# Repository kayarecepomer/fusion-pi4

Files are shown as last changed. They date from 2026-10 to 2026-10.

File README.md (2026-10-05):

# fusion-pi4: foldable PiDeck cyberdeck

A remix of the [PiDeck 7-inch cyberdeck with Raspberry Pi 5](https://makerworld.com/en/models/2619704-pideck-7-inch-cyberdeck-with-raspberry-pi-5)
into a foldable, small-laptop form factor. It reuses the original build's parts
(7" display, keyboard, Raspberry Pi 5, screws and hardware); only the printed
enclosure changes, splitting into a screen lid and a keyboard base joined by a hinge.

Designed in Autodesk Fusion.

## Repository layout

| Folder | Contents |
|---|---|
| `cad/fusion/` | Native Fusion archives (`.f3d`, or `.f3z` for multi-component designs). The editable source of truth. |
| `cad/cadquery/` | Parametric CadQuery script that generates the STEP and STL files. |
| `cad/step/` | STEP exports (`.step`) so the model opens in any CAD tool. |
| `stl/` | Print-ready meshes (`.stl` or `.3mf`), one file per printed part. |
| `docs/` | Notes, the export guide and the design report. |

## Getting the model

- **Edit it:** open `cad/fusion/*.f3d` in Fusion via *File > Open > Open from my computer*.
- **Other CAD tools (FreeCAD, Onshape, SolidWorks):** import `cad/step/*.step`.
- **Print it:** slice the files in `stl/`.

## Adding new work

See [docs/exporting-from-fusion.md](docs/exporting-from-fusion.md) for how to
export from Fusion and which file goes where.

## Current design (draft 3)

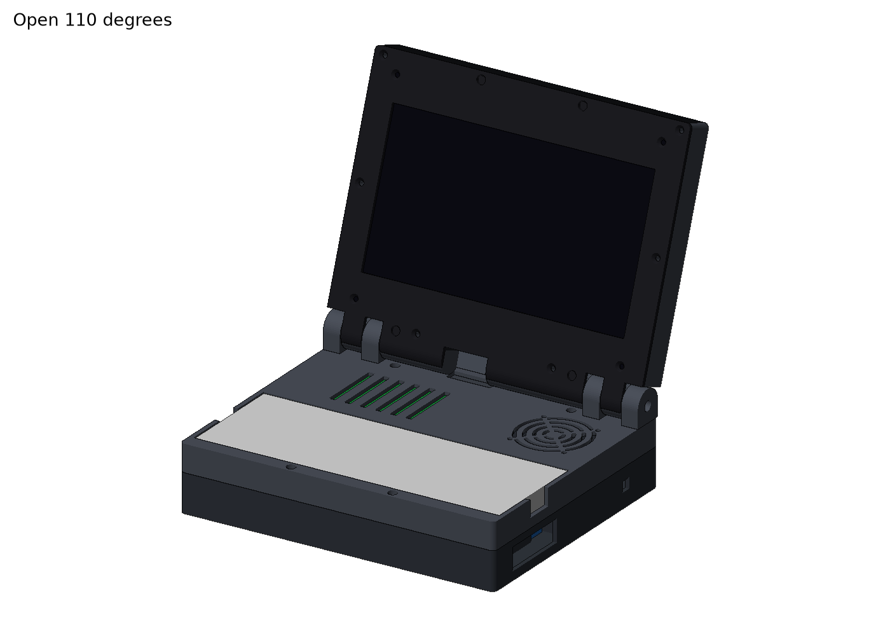
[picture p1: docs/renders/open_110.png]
open


The first draft is a parametric [CadQuery](https://cadquery.readthedocs.io) script in
`cad/cadquery/`, sized from PiDeck V1's own STEP assembly. It writes the STEP files to
`cad/step/` and the print-ready STLs to `stl/`. The design report is in
[docs/foldable-laptop-report.md](docs/foldable-laptop-report.md).

```bash
pip install cadquery
python cad/cadquery/foldable_laptop.py && python cad/cadquery/check_fit.py && python cad/cadquery/render.py
```

## License

Remix of PiDeck by Screase3D, shared under the same CC BY-NC-SA 4.0 license.

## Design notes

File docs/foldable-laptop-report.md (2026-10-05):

# Foldable PiDeck: design report (draft 3)

A clamshell remix of the [PiDeck 7" cyberdeck](https://makerworld.com/en/models/2619704-pideck-7-inch-cyberdeck-with-raspberry-pi-5)
that keeps PiDeck's parts (Raspberry Pi 5 + Waveshare NVMe HAT, 7" IPS touch LCD,
Rii X1 mini keyboard, Anker power bank, M2.5 screws + heat-set inserts, 5x2 magnets)
but folds like a small laptop.

Part sizes are measured from PiDeck V1's own STEP assembly
(`Pi_Deck_RaspberryPi5.step`, see `docs/components.md`). Draft 3 drops PiDeck's
Waveshare IO adapter in favour of short cables, as kaya chose, which makes the base
20 mm shallower.

open

## 1. What is in this draft

| File | What it is |
|---|---|
| `cad/cadquery/foldable_laptop.py` | The whole model as a parametric CadQuery script. All bought-part sizes sit in one `Parts` block. |
| `cad/cadquery/check_fit.py` | Checks every printed part is one valid solid, that no part collides with the keyboard, power bank, Pi block or display, and that the lid swings 0 to 150 degrees without hitting the base. |
| `cad/cadquery/render.py` | Makes the PNG previews in `docs/renders/` (software renderer, no GPU needed). |
| `cad/step/*.step` | One STEP per printed part, plus `foldable-assembly-closed.step` and `foldable-assembly-open.step` (110 degrees) with the bought parts as coloured dummies. |
| `stl/*.stl` | Print-ready meshes, already rotated into print orientation. |

Rebuild everything after changing a number:

```bash
pip install cadquery
python cad/cadquery/foldable_laptop.py   # STEP into cad/step/, STL into stl/
python cad/cadquery/check_fit.py         # must end with "ALL OK"
python cad/cadquery/render.py            # refresh docs/renders/*.png
```

### Opening it in Fusion

Use **File > Open > Open from my computer** (or Upload in the Data Panel) on
`cad/step/foldable-assembly-closed.step`. Fusion imports STEP as real B-rep bodies, one
component per part, so you can sketch on faces, add fillets and move holes like a
native design. If you carry on in Fusion, export the `.f3d` into `cad/fusion/` as
described in `docs/exporting-from-fusion.md`. The script stays the source of truth for the big dimensions; Fusion is
the right place for styling (chamfers, logos, texture) once the layout is settled.

## 2. Overall layout

| | Draft 3 (no IO adapter) | Draft 2 (with IO adapter) | Draft 1 (datasheet guesses) |
|---|---|---|---|
| Footprint (base and lid) | **186 x 154 mm** | 186 x 174 | 180 x 136 |
| Base height | **38.2 mm** | 38.2 | 36.8 |
| Lid thickness | **18.6 mm** | 18.6 | 15.5 |
| Closed thickness | **56.8 mm** | 56.8 | 52.3 |
| Open angle tested | 0 to 150 degrees, no collisions | same | same |

What changed the size:
- The keyboard is **179.4** mm wide (not 152), so the case is 186 wide.
- The screen module is **124.2** mm tall and **14.1** thick including its driver board
  (not 100 x 11), so the lid is deeper and thicker.
- PiDeck's "IO board" is an adapter that plugs into the Pi's micro-HDMI and USB-C edge
  and sticks out 34.6 mm past it. Without it, the Pi + HAT block is
  **90 x 58 x 26.1** mm. The depth (154 mm) is now set by the lid: the 124.2 mm screen
  plus the hinge.

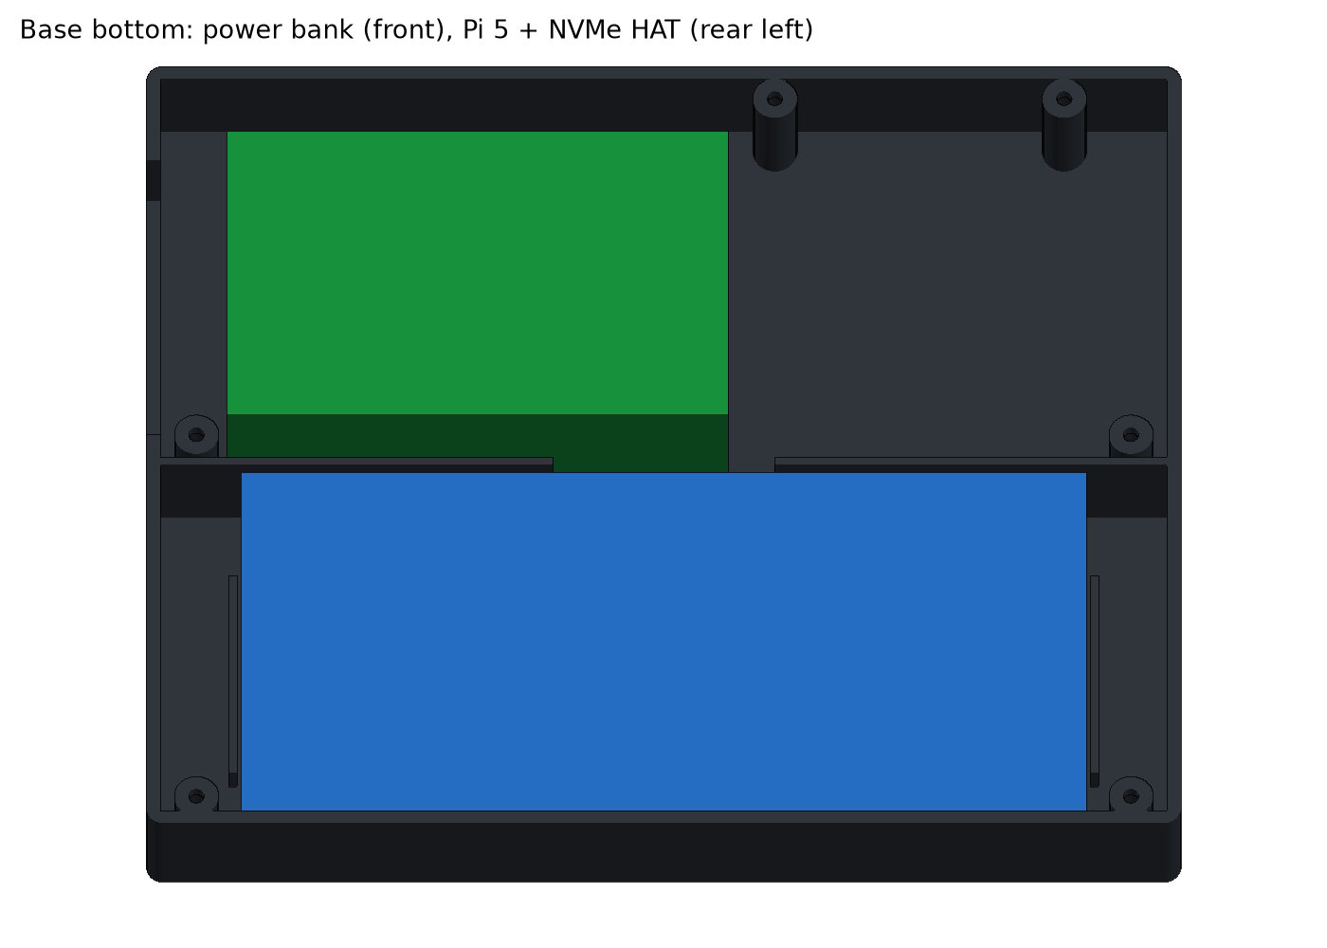
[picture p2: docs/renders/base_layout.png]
layout


**Base, front half:** the power bank lies flat in a bay on the floor. The keyboard
sits on top of it in a pocket in the deck, flush with the surface so the lid closes
flat. Thumb scoops at both ends of the pocket let you lift the keyboard out.

**Base, rear half:** the Pi + HAT sits rear-left, right behind the keyboard, on four
standoffs with M2.5 heat-set inserts (the SSD hangs under the HAT between them). Its
USB and Ethernet ports face the left wall; the Pi sits 12 mm in from the wall behind an
I/O window, so plugs with chunky overmoulds still fit. Its micro-HDMI and USB-C edge
faces the hinge with a 15.7 mm gap for right-angle plugs: the display ribbon goes
straight up from the micro-HDMI port through the hinge, and the USB-C is fed from the
power bank inside. The right-rear bay holds the optional 4010 fan (under a grill in the
deck), the 6x6 power button in the right wall, and the wiring. A window in the right
wall reaches the power bank's port.

**Lid:** the screen sits face down in the lid when closed, held between a 2 mm bezel
and pressure pads on the back shell. Corner locators centre it, and its own four
mounting holes (157.0 x 114.9 pattern) line up with countersunk M2.5 holes in the bezel,
so it can be screwed in with nuts on the back of the frame. The chin under the screen
(next to the hinge) is about 22 mm.

**Latch:** the 8 magnets from the PiDeck kit are reused as 4 pairs, two at the front
edge and two near the hinge, pressed into blind pockets in the deck and the bezel.

## 3. Printed parts

| Part | Print size (mm) | Orientation | Fasteners |
|---|---|---|---|
| `base-bottom` | 186 x 154 x 22.5 | floor down | 6x M2.5x8 countersunk, from deep counterbores in the underside up into `base-top` |
| `base-top` | 186 x 154 x 15.7 | deck face down, no supports | 6 heat-set inserts |
| `hinge-knuckle-left/right-outer`, `hinge-knuckle-left/right-inner` (4 parts) | 18.6 x 18.6 x 10 | on their side, bore vertical | 2x M2.5x8 each from under the deck, insert in the knuckle |
| `lid-back` | 186 x 154 x 16.6 | back plate down | 6 heat-set inserts |
| `lid-bezel` | 186 x 151 x 3 | face down | 6x M2.5x6 countersunk, plus 4x M2.5 + nuts through the screen's holes |

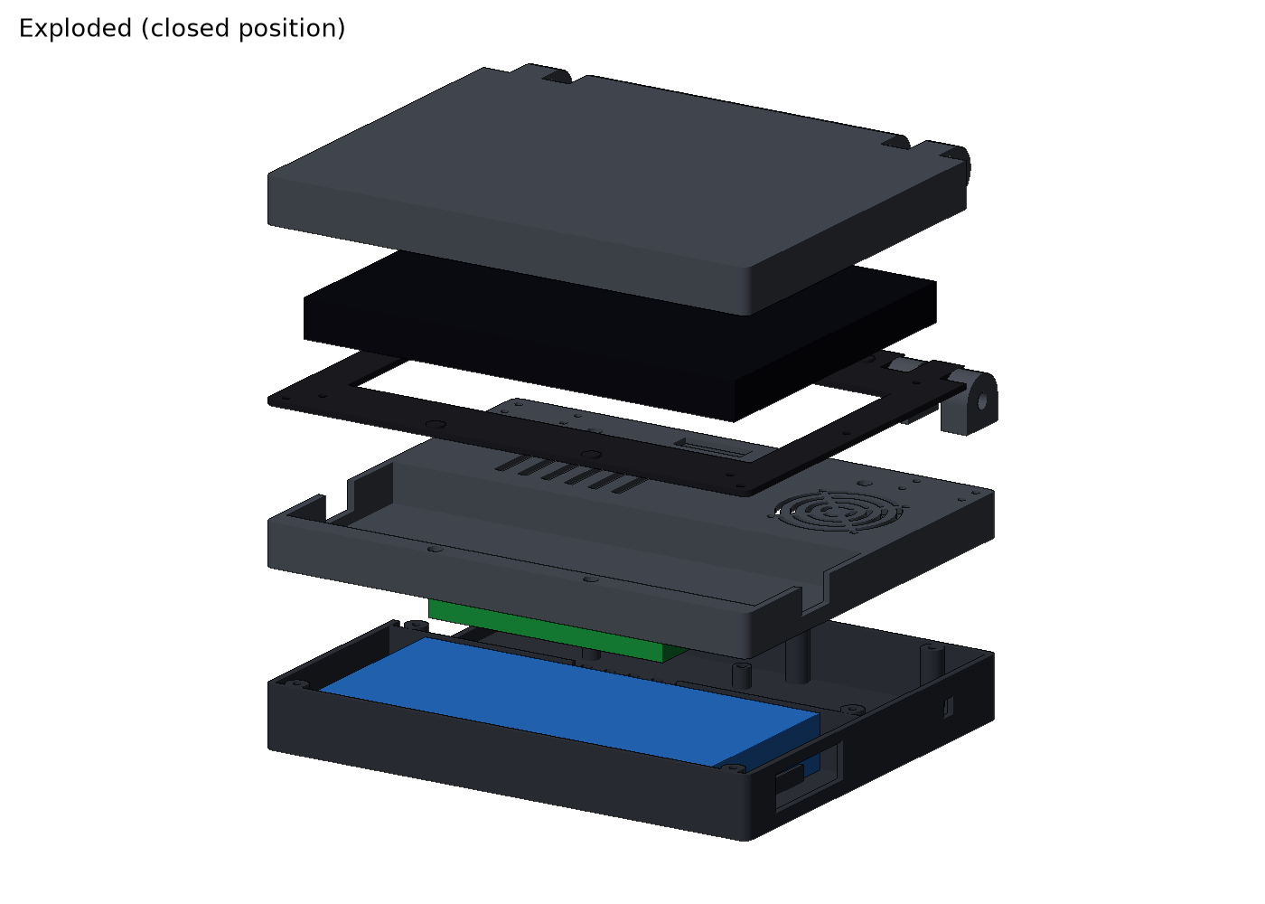
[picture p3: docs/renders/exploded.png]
exploded


The big parts need a bed of at least 190 x 160 mm (Bambu A1/P1/X1, Prusa MK4 and
Core One all work; an A1 mini is too small). The hinge knuckles are separate parts on
purpose: welded to `base-top` they would stick up above the deck and stop it printing
flat.

## 4. Hinge and cable path

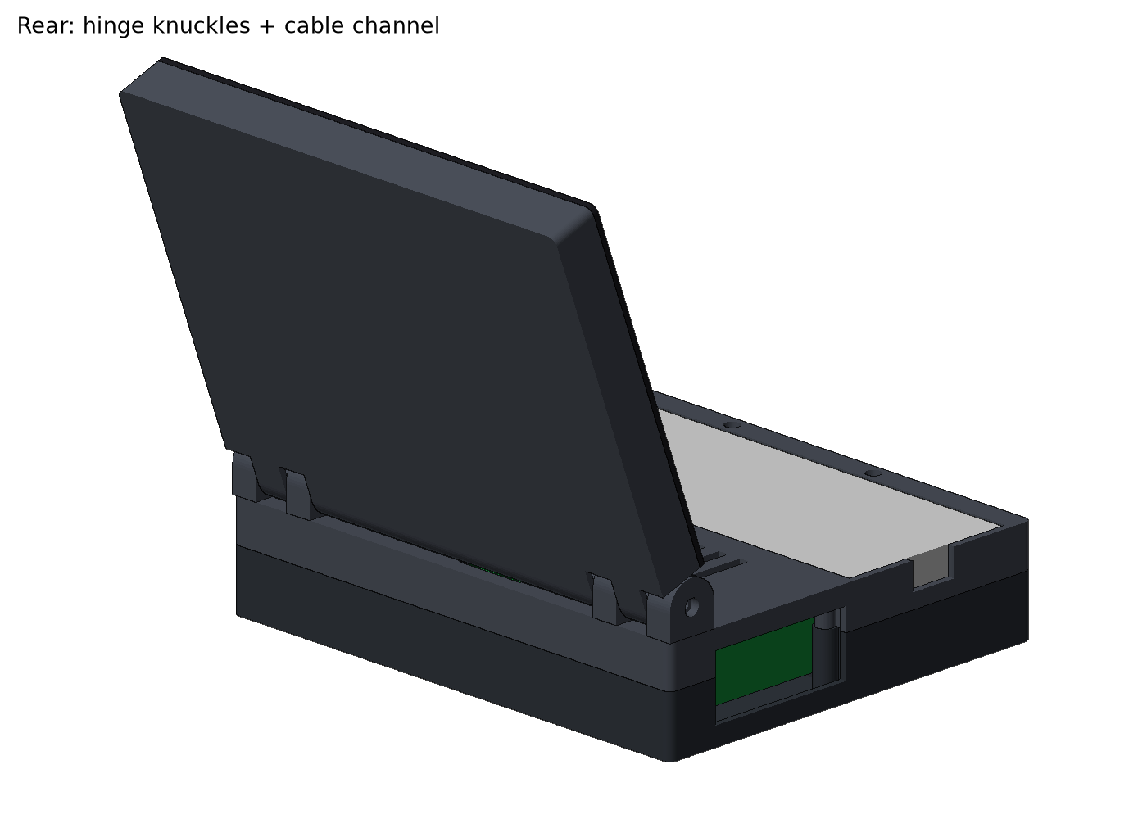
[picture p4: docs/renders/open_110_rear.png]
rear


- **Type:** a barrel hinge with three knuckles on each side (base, lid, base). The
  hinge axis sits at the middle of the lid's thickness, 9.3 mm in from the back edge,
  and the lid's back edge is a full half-round around that axis, so the lid never digs
  into the base at any angle (checked by `check_fit.py`).
- **Pin:** one M3x30 socket-head bolt per side. It goes in through the outer knuckle
  (3 mm head recess, so it sits flush) and screws into an M3 nut trapped in the inner
  knuckle. The lid knuckle has a 3.3 mm clearance bore and the base knuckles a 3.0 mm
  bore. Tightening the bolt adds friction so the screen stays where you put it. If it
  is too loose, a nylon washer or a nyloc nut is the next step before a real friction
  hinge.
- **Cable channel:** a 26 mm gap in the hinge, centred 10 mm left of the middle so it
  lands right above the Pi's micro-HDMI ports. The lid's rounded back edge is open there, and there
  is a 26 x 8 mm slot in the deck just in front of the axis.
- **Cable choice:** a normal HDMI lead will not survive bending in the hinge. Use a
  flat FPC HDMI ribbon (the "FPV HDMI" kits) with a 90 degree **micro-HDMI** head on
  the Pi and a full-size HDMI head on the screen, plus a thin USB lead for touch (or a
  short flat USB ribbon). Power goes from the power bank to the Pi's USB-C with a short
  right-angle USB-C cable. Leave a loose loop on the
  base side so the cable isn't pulled tight when the lid opens.

## 5. Parameters and where they came from

All of these are in the `Parts` dataclass at the top of `cad/cadquery/foldable_laptop.py`.

| Parameter | Value | Source |
|---|---|---|
| Keyboard | 179.4 x 64.9 x 13.9 | PiDeck STEP (Rii X1 rounded-edge model). Riitek lists 150 x 60 x 10 for the key body, so confirm with calipers. |
| Screen module | 166.0 x 124.2 x 14.1 | PiDeck STEP |
| Screen holes | 4x d3.3 on 157.0 x 114.9 | PiDeck STEP |
| Visible area (bezel window) | 154.2 x 86, centred | **Guess**: the STEP screen is one solid. Measure the real panel. |
| Pi + HAT stack | 90.1 x 57.7 x 26.1 | PiDeck STEP |
| Power bank | 152.0 x 69.0 x 19.5 | PiDeck STEP (Anker PowerCore III 10K) |
| Heat-set insert hole | 3.4 dia, 4.5 deep | M2.5 x 3.5 x 4 inserts; PiDeck's own bores are 3.5 to 3.9, so tune for your printer |

## 6. Known issues and next steps

1. **Thickness.** The base is 38.2 mm. Swapping the power bank for PiDeck V2's USB-C PD
   module only gets it down to about 32 to 35 mm, because the 26.1 mm Pi + NVMe stack
   then sets the height. Getting it really thin means dropping the NVMe HAT or laying
   the SSD beside the Pi.
2. **No external HDMI any more.** The IO adapter gave two full-size HDMI ports; now
   both micro-HDMI ports are inside. If you want an external monitor, add a short
   panel-mount micro-HDMI to HDMI extension through the left wall.
3. **Visible area of the screen is a guess.** Measure it before printing the bezel.
4. **Pin friction is untested.** Print the four knuckles and a strip of lid first as a
   test (about 20 minutes) before the large parts.
5. **The I/O window is one generous opening.** Tighten it around the real ports after a
   test fit, or cover it with a magnetic flap like PiDeck does.
6. **The standoff positions assume the SSD fits between them** (it sits under the HAT).
   Check against the real HAT before printing `base-bottom`.
7. **No feet yet.** Add four 10 mm rubber-foot recesses to `base-bottom` in Fusion.

## 7. Bill of materials changes vs. PiDeck

| Item | PiDeck V1 | This remix |
|---|---|---|
| M2.5 countersunk screws | ~17x M2.5x6, 2x M2.5x8, 4x M2.5x5 | 6x M2.5x6 + 4x M2.5 (screen) in the lid, 14x M2.5x8 in the base and knuckles, Pi screws as in PiDeck |
| M2.5 heat-set inserts | ~27 | 6 (base-top) + 8 (knuckles) + 6 (lid-back) + 4 (Pi) = 24 |
| 5x2 magnets | 8 | 8 (4 latch pairs) |
| M3 screws | 4x M3x16 + nuts (fan) | same, **plus 2x M3x30 socket head + 2x M3 nuts (hinge pins)** |
| Waveshare IO adapter | yes | **not used** |
| Display cable | standard HDMI via the IO adapter | **flat FPC ribbon, 90 degree micro-HDMI head to HDMI (new)** |
| Pi power | USB-C via the IO adapter | **short right-angle USB-C cable from the power bank (new)** |

## 8. License

PiDeck is CC BY-NC-SA 4.0, so this remix is shared under the same license, credited to
Screase3D.

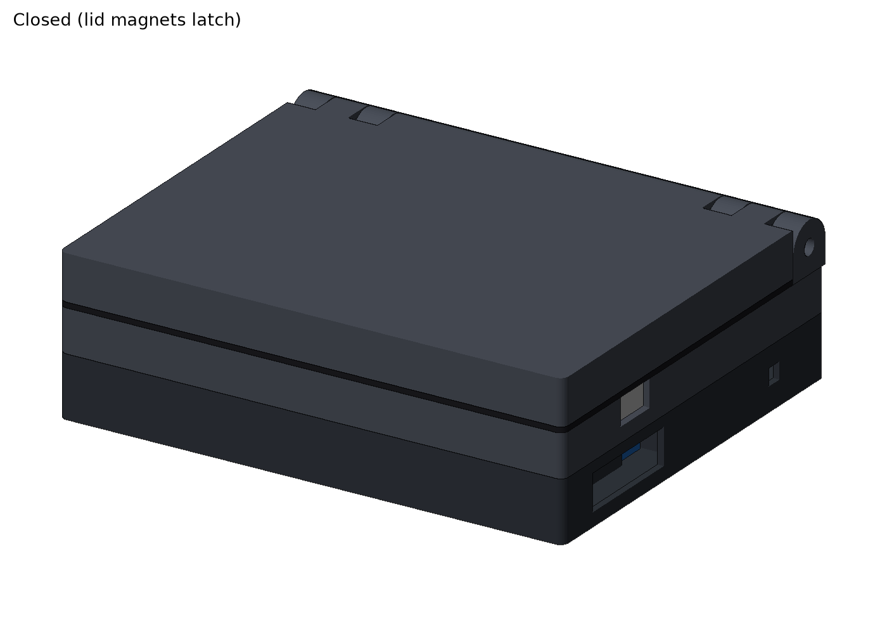
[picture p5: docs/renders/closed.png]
closed


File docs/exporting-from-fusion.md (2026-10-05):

# Exporting work from Fusion into this repo

Fusion keeps designs in the Autodesk cloud, so nothing lands in this repo until
you export it. Each design should be committed in three forms.

## 1. Native archive (`cad/fusion/`)

1. Open the design in Fusion.
2. *File > Export*.
3. Type: **Fusion Archive Files (\*.f3d)**. If the design references other
   designs (linked components), choose **Fusion Archive Files (\*.f3z)** so
   the references are bundled.
4. Save as `cad/fusion/<part-name>.f3d`.

This is the file to open when you want to keep editing with full history,
sketches and parameters.

## 2. STEP (`cad/step/`)

1. *File > Export*, type **STEP Files (\*.step)**.
2. Save as `cad/step/<part-name>.step`.

STEP keeps exact solid geometry and opens in any CAD tool, but loses the
timeline and parameters.

## 3. Print meshes (`stl/`)

1. In the browser tree, right-click each body you will print, then
   *Save As Mesh* (or *File > 3D Print* with "Send to 3D print utility" off).
2. Format **STL (Binary)** or **3MF**, refinement **High**, units **mm**.
3. Save one file per printed part, e.g. `stl/lid.stl`, `stl/base.stl`,
   `stl/hinge-left.stl`.

Export each part in the orientation you intend to print it, flat face down.

## Naming

Use lowercase, hyphen-separated names that describe the part
(`base-bottom`, `screen-bezel`, `hinge-pin`). Keep the same name across the
`.f3d`, `.step` and `.stl` versions of a part.

## Committing

```bash
git add cad stl docs
git commit -m "Add <part-name> v<n>"
git push
```

Or drag the files into the GitHub web page for the matching folder
(*Add file > Upload files*). Files over 100 MB need Git LFS; Fusion parts
are normally far smaller.

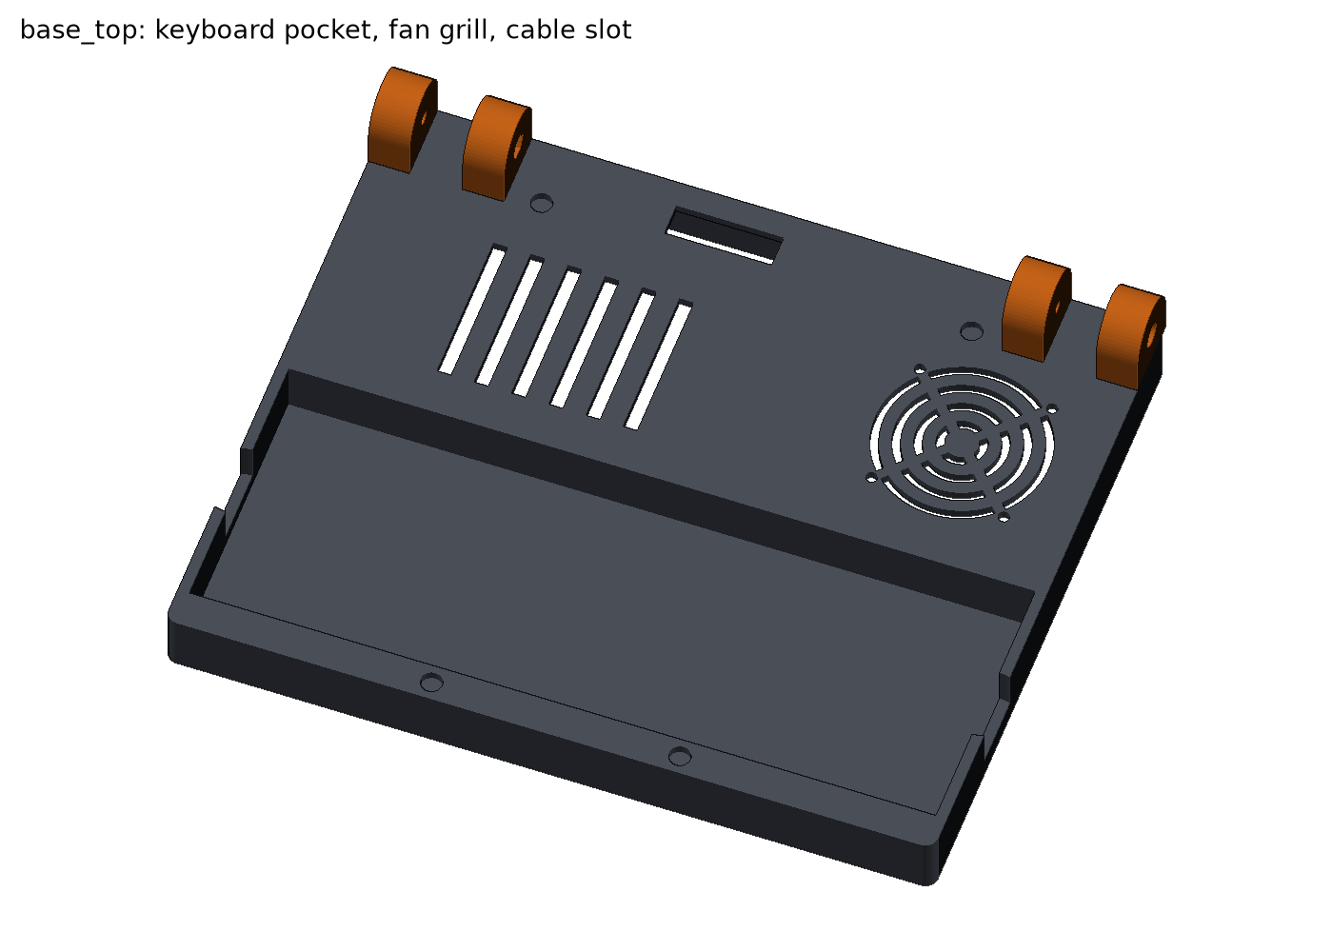
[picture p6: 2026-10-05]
docs/renders/base_top.png

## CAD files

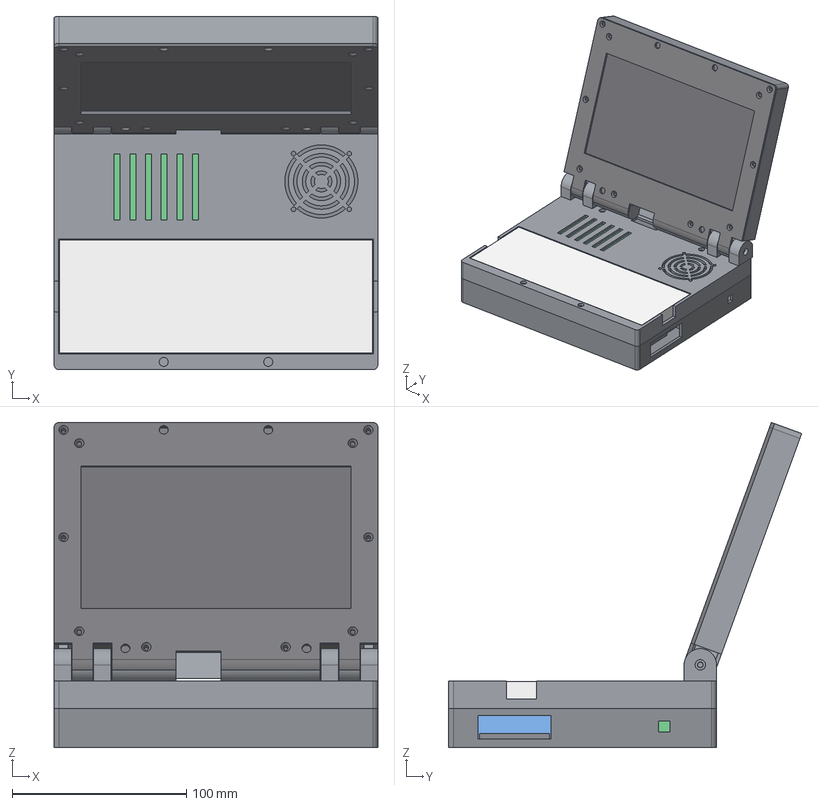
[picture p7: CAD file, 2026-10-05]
cad/step/foldable-assembly-open.step
186.0 x 202.9 x 186.7 mm
base_bottom
base_top
knuckle_R_outer
knuckle_R_inner
knuckle_L_outer
knuckle_L_inner
lid_bezel
lid_back
keyboard
powerbank
pi5_stack
display

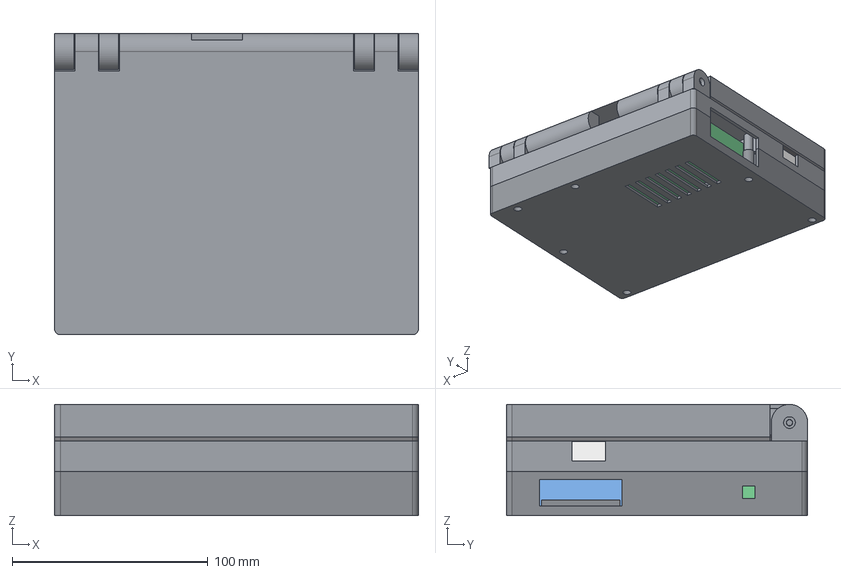
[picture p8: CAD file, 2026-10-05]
cad/step/foldable-assembly-closed.step
186.0 x 154.0 x 56.8 mm
base_bottom
base_top
knuckle_R_outer
knuckle_R_inner
knuckle_L_outer
knuckle_L_inner
lid_bezel
lid_back
keyboard
powerbank
pi5_stack
display

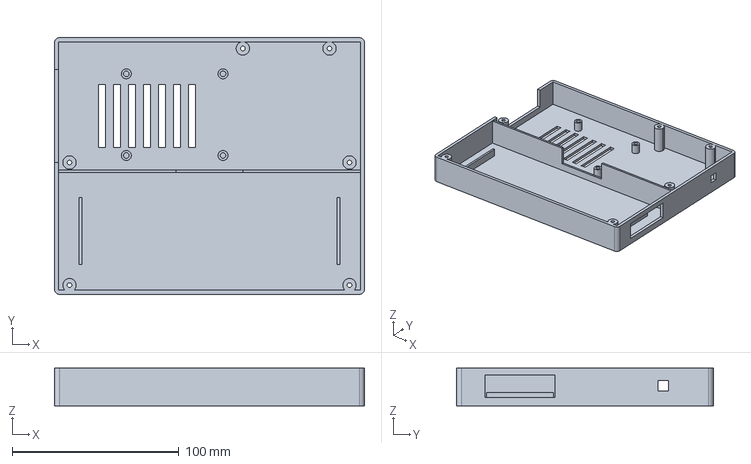
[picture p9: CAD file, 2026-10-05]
cad/step/base-bottom.step
186.0 x 154.0 x 22.5 mm

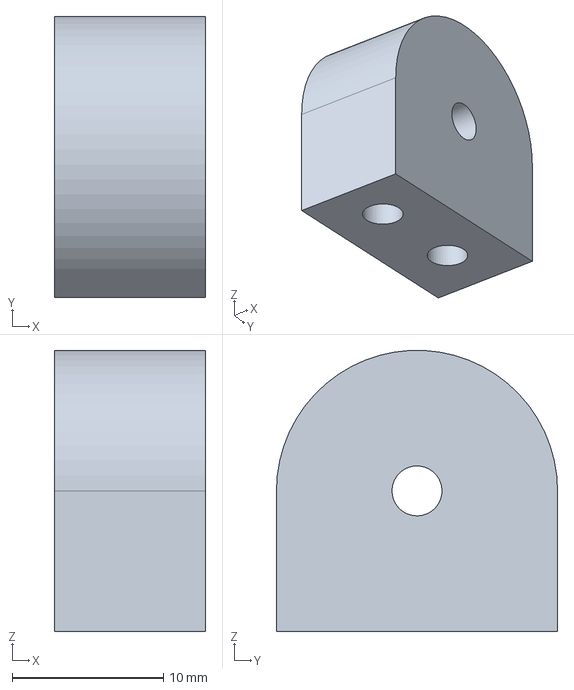
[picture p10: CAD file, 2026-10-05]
cad/step/hinge-knuckle-left-outer.step
10.0 x 18.6 x 18.6 mm

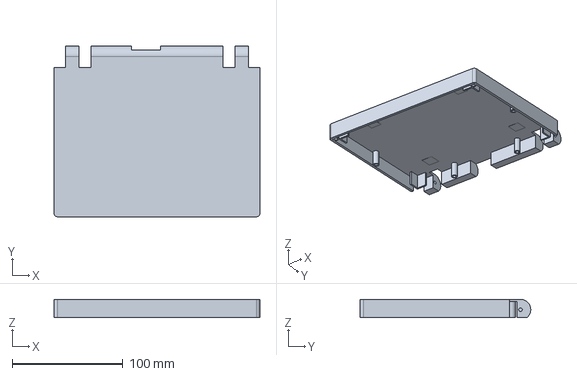
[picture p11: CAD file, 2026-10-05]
cad/step/lid-back.step
186.0 x 154.0 x 16.6 mm

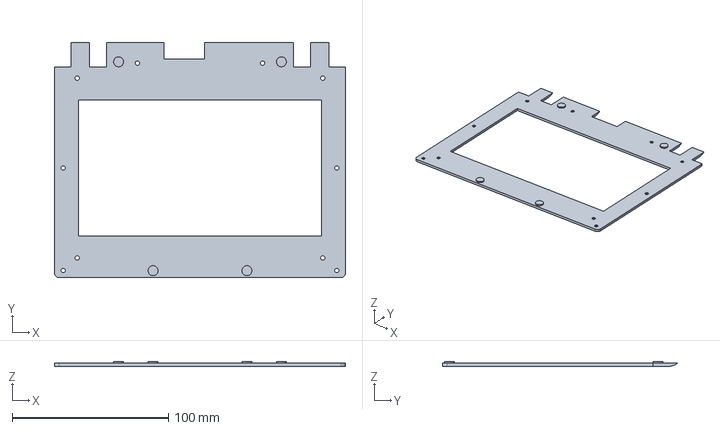
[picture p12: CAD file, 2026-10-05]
cad/step/lid-bezel.step
186.0 x 150.5 x 3.00 mm

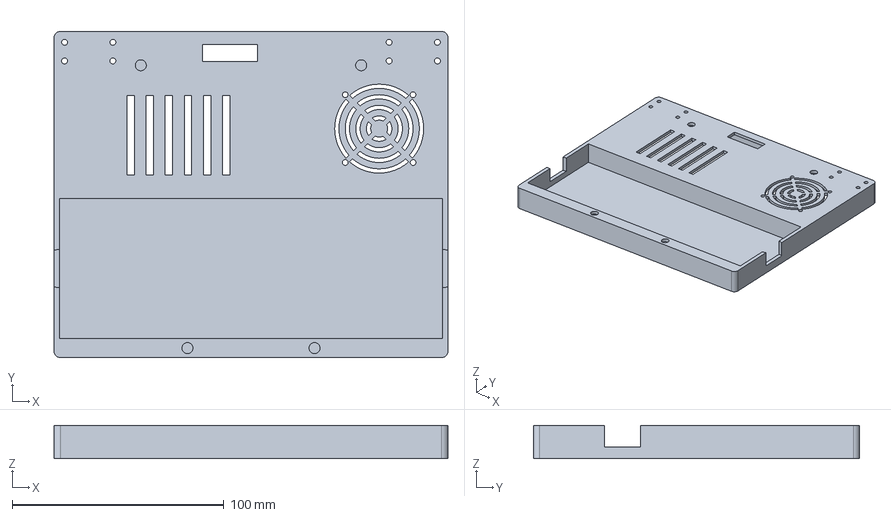
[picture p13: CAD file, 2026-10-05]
cad/step/base-top.step
186.0 x 154.0 x 15.7 mm

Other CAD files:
cad/step/hinge-knuckle-left-inner.step
cad/step/hinge-knuckle-right-inner.step
cad/step/hinge-knuckle-right-outer.step
stl/base-bottom.stl
stl/base-top.stl
stl/hinge-knuckle-left-inner.stl
stl/hinge-knuckle-left-outer.stl
stl/hinge-knuckle-right-inner.stl
stl/hinge-knuckle-right-outer.stl
stl/lid-back.stl
stl/lid-bezel.stl

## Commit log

2026-10-05 Set up repo layout and Fusion export guide
    Add folders for Fusion archives, STEP exports and print meshes, a README
    describing the foldable PiDeck remix, and a guide for exporting work from
    Fusion into the repo.
2026-10-05 Add parametric foldable-laptop model (CadQuery), STEP/STL exports, renders and report
    Two-part base (power bank bay under a flush keyboard deck, Pi 5 + NVMe HAT +
    IO adapter block rear-left), two-part lid (bezel + back), four bolt-on hinge
    knuckles on M3 pins with a cable channel. Part sizes measured from the PiDeck
    V1 STEP assembly. Includes fit and hinge-swing checks.
    [base-bottom.step, base-bottom.stl, base-top.step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]
2026-10-05 Drop the IO adapter: short cables from the Pi, base 20 mm shallower
    The Pi's micro-HDMI/USB-C edge now faces the hinge with room for
    right-angle plugs; the display ribbon goes straight up through a cable
    channel above the micro-HDMI ports. Footprint 186 x 154 mm.
    [base-bottom.step, base-bottom.stl, base-top.step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]
